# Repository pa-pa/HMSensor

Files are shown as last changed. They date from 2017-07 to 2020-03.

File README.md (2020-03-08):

# HMSensor

Flexible and tiny (40x20mm) Hardware Platform for 868MHz Sensors and Actors.

It comes in tow different variants:
* StepUp: For Batter or PowerSupply usage
* CR2032: For even smaller coin battery applications

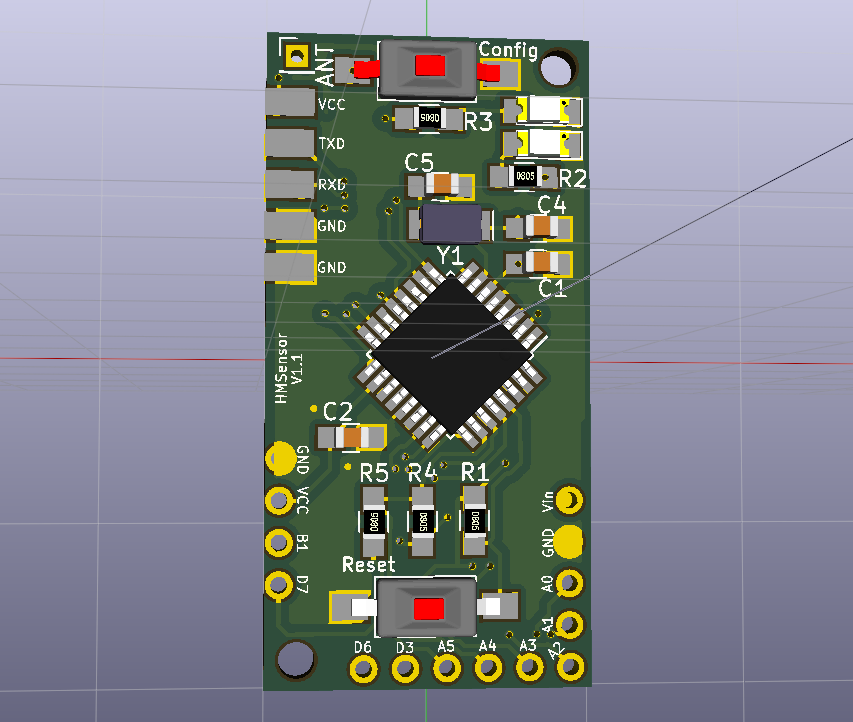
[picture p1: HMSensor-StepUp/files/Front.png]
HMSensor-StepUp


Extensible with [AddOn-Boards](AddOns).

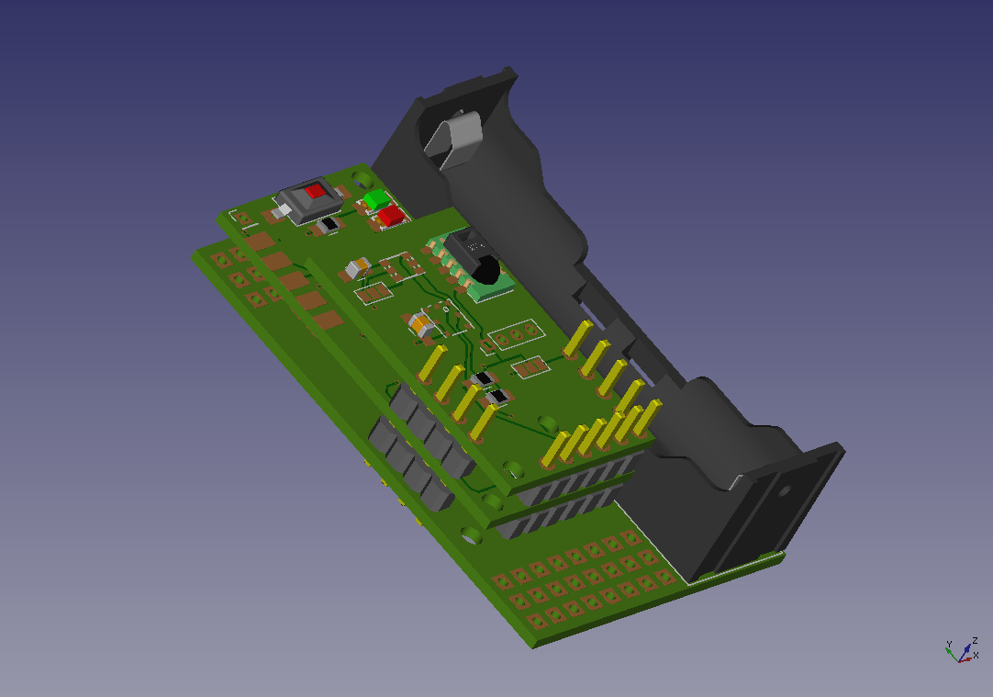
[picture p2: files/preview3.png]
AddOn Example


* Some (german) documentation is available at https://asksinpp.de/Projekte/psi/HMSensor
* Helper PCB for flashing: https://github.com/psi-4ward/HMSensor-FlashStation

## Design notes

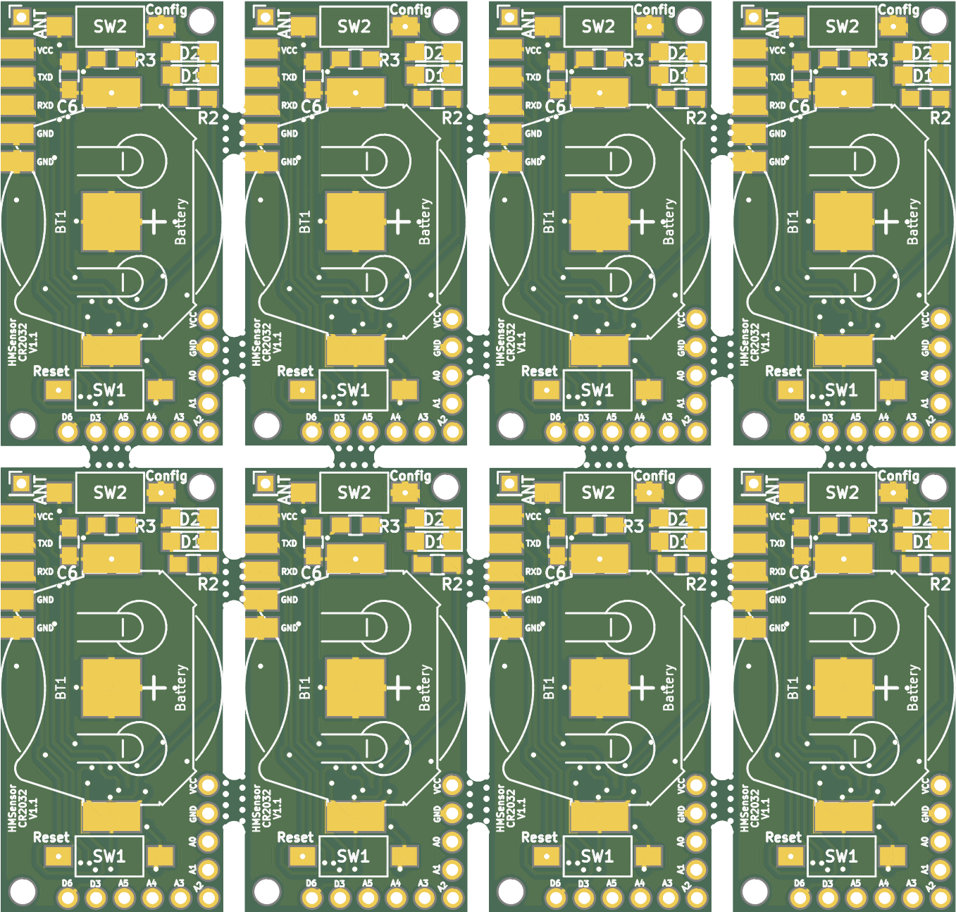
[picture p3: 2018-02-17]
HMSensor-CR2032/panel10/Untitled_Combined_Top.png

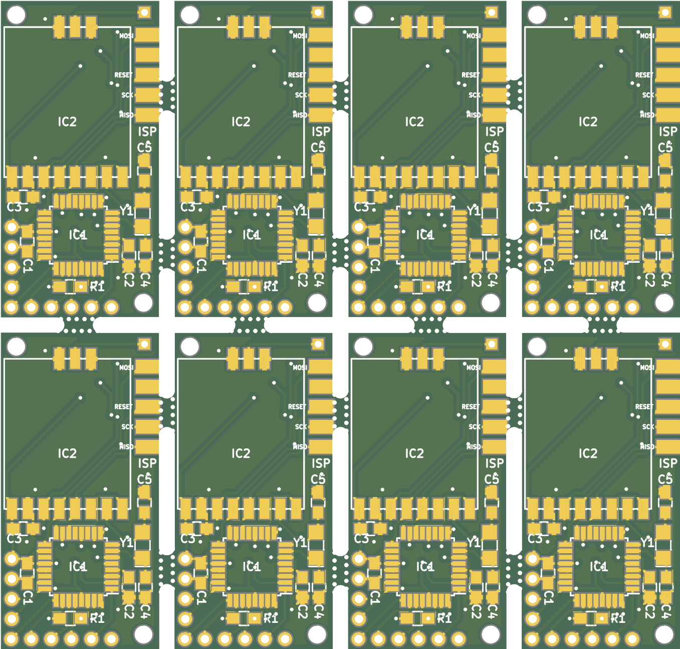
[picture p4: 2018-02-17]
HMSensor-CR2032/panel10/Untitled_Combined_Bottom.png

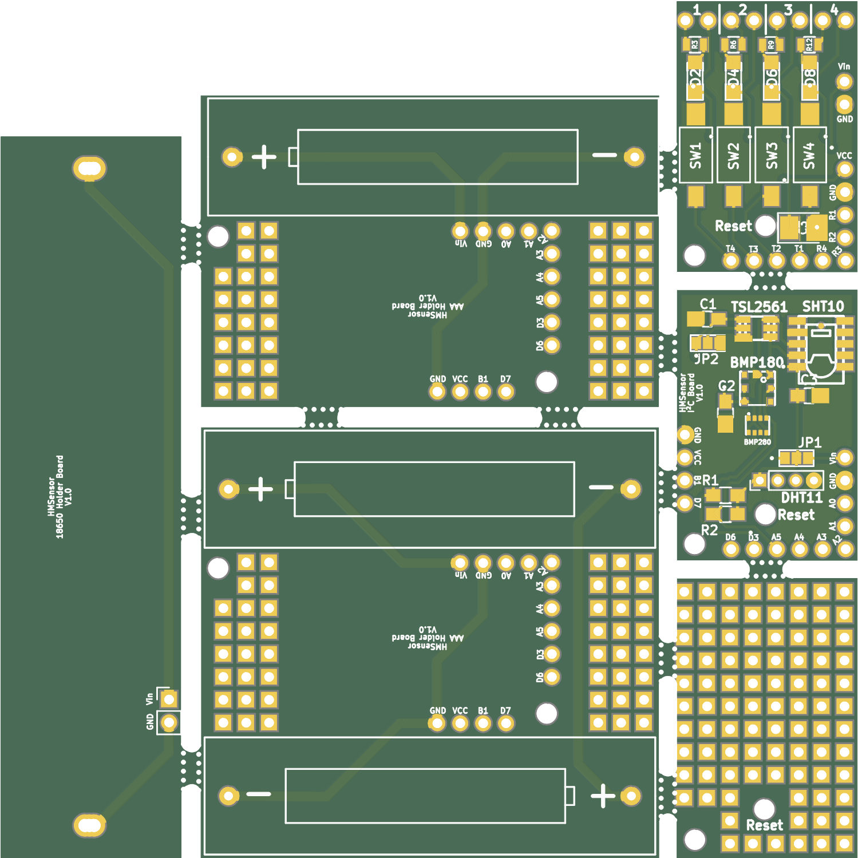
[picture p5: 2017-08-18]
Panel2/Untitled_Combined_Top.png

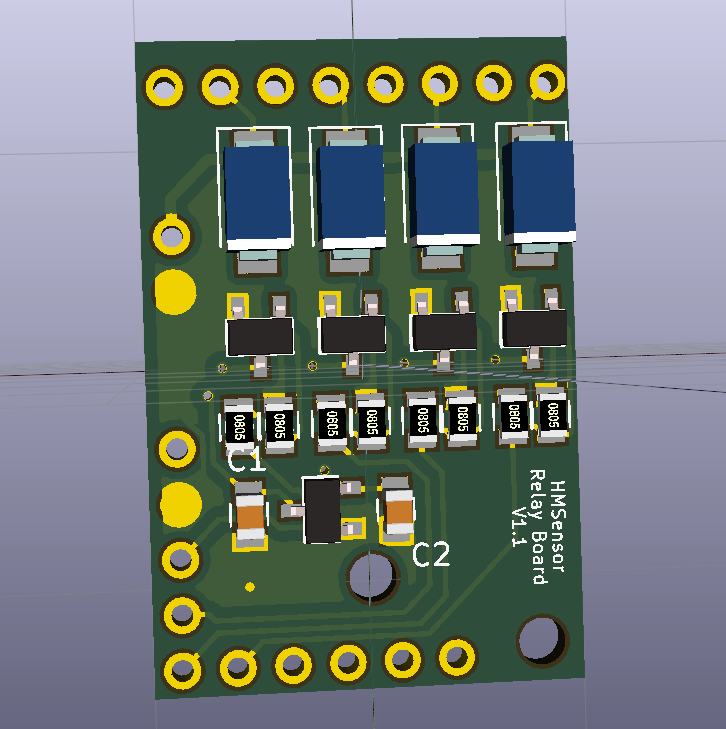
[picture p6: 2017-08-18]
AddOns/RelayBoard/files/RelayBoard-Back.png

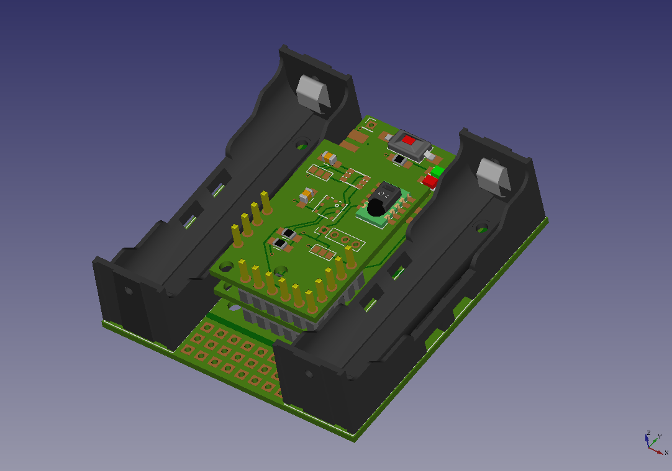
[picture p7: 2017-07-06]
files/preview2.png

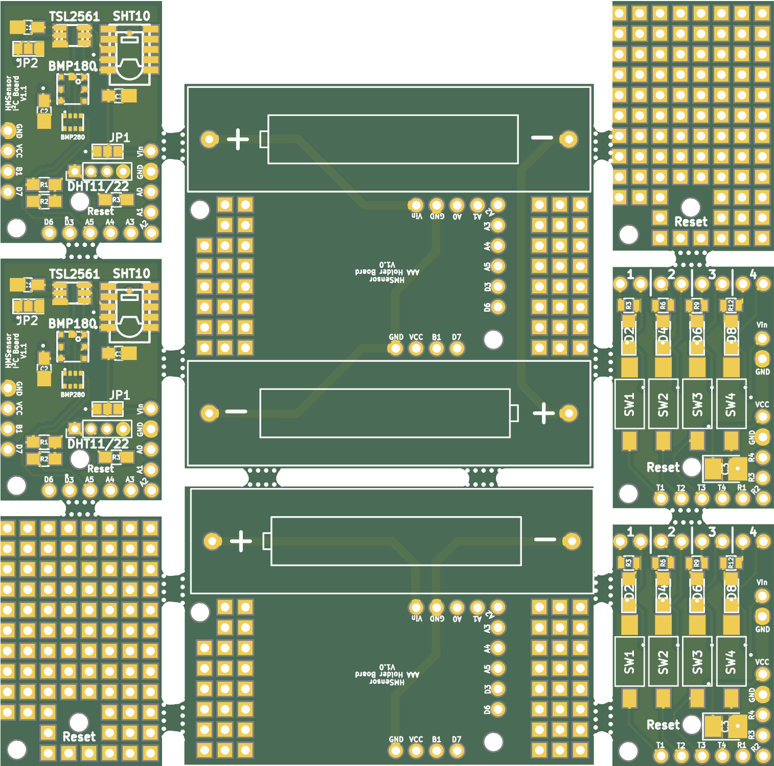
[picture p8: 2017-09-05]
Panel/P1_Combined_Top.png

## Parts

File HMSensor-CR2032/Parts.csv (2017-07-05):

Id | Designator | Package | Quantity | Designation | Supplier and ref
1 | P4 | Pin_Header_Straight_1x05_Pitch2.54mm_SMD_BySide | 1 | ISP Bottom
2 | P5 | Pin_Header_Straight_1x05_Pitch2.54mm_SMD_BySide | 1 | ISP Top
3 | IC1 | TQFP-32_7x7mm_Pitch0.8mm | 1 | ATMEGA328P-A
4 | P1 | Pin_Header_Straight_1x04_Pitch2.54mm | 1 | Contacts
5 | P2 | Pin_Header_Straight_1x06_Pitch2.54mm | 1 | Contacts
6 | BT1 | AB2_20MM_COIN_CELL_SMD | 1 | Battery
7 | IC2 | CC1101_Module | 1 | CC1101
8 | SW1 | SW_SPST_FSMSM | 1 | Reset
9 | SW2 | SW_SPST_FSMSM | 1 | Config
10 | C1,C2,C3 | C_0805_HandSoldering | 3 | 100n
11 | D1 | LED_1206 | 1 | LED Red
12 | D2 | LED_1206 | 1 | LED Green
13 | R1 | R_0805_HandSoldering | 1 | 10k
14 | R2,R3 | R_0805_HandSoldering | 2 | 1k5
15 | C4,C5 | C_0805_HandSoldering | 2 | 9p
16 | Y1 | Crystal_SMD_MicroCrystal_CC7V-T1A-2pin_3.2x1.5mm_HandSoldering | 1 | 32kHz
17 | REF**,REF** | MountingHole_2.2mm_M2 | 2 | MountingHole_2.2mm_M2
18 | P3 | Pin_Header_Straight_1x01_Pitch2.00mm | 1 | ANT
19 | C6 | C_0805_HandSoldering | 1 | 10µ

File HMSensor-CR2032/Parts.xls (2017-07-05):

Id | Designator | Package | Quantity | Designation | Supplier and ref
1 | P4 | Pin_Header_Straight_1x05_Pitch2.54mm_SMD_BySide | 1 | ISP Bottom
2 | P5 | Pin_Header_Straight_1x05_Pitch2.54mm_SMD_BySide | 1 | ISP Top
3 | IC1 | TQFP-32_7x7mm_Pitch0.8mm | 1 | ATMEGA328P-A | https://www.aliexpress.com/item/Free-Shipping-ATMEGA328P-AU-ATMEGA328P-ATMEGA328-8-bit-microcontroller-AVR-32-k-flash-memory-QFP-32/1913432637.html
4 | P1 | Pin_Header_Straight_1x04_Pitch2.54mm | 1 | Contacts
5 | P2 | Pin_Header_Straight_1x06_Pitch2.54mm | 1 | Contacts
6 | BT1 | AB2_20MM_COIN_CELL_SMD | 1 | Battery | https://www.aliexpress.com/item/50pcs-SMD-Tab-20mm-CR2032-2032-Battery-Button-Cell-Holder-Coin-Cell-Retainer-Battery-Holder-surface/32732961416.html
7 | IC2 | CC1101_Module | 1 | CC1101 | https://www.aliexpress.com/item/CC1101-Wireless-Module-Long-Distance-Transmission-Antenna-868MHZ-M115-Free-Shipping/32673344379.html
8 | SW1 | SW_SPST_FSMSM | 1 | Reset | https://www.aliexpress.com/item/Tact-Switch-SMD-small-button-touch-of-a-button-3-6-2-5MM-feet-3-6/32605670895.html
9 | SW2 | SW_SPST_FSMSM | 1 | Config | https://www.aliexpress.com/item/Tact-Switch-SMD-small-button-touch-of-a-button-3-6-2-5MM-feet-3-6/32605670895.html
10 | C1,C2,C3 | C_0805_HandSoldering | 3 | 100n | https://www.aliexpress.com/item/100pcs-lot-100nF-X7R-Error-10-50V-0805-SMD-Thick-Film-Chip-Multilayer-Ceramic-Capacitor-free/32318938808.html
11 | D1 | LED_1206 | 1 | LED Red | https://de.aliexpress.com/item/100PCS-LOT-1206-Red-SMD-LED-Diode-Light-3216-Diodes-SMD-Super-Bright-1206-led-3/32623813733.html
12 | D2 | LED_1206 | 1 | LED Green | https://de.aliexpress.com/item/100PCS-LOT-1206-Green-SMD-LED-Diode-Light-3216-Diodes-SMD-Super-Bright-1206-led-3/32623837500.html
13 | R1 | R_0805_HandSoldering | 1 | 10k | https://www.aliexpress.com/item/SMD-Resistance-0805-10k-1-1-8W-Chip-Resistors-100PCS-LOT/32520849440.html
14 | R2,R3 | R_0805_HandSoldering | 2 | 1k5 | https://www.aliexpress.com/item/Free-shipping-100pcs-lot-SMD-Chip-Resistor-1-0805-1-5K-1500-OHMS-1-8W-100/32568078790.html
15 | C4,C5 | C_0805_HandSoldering | 2 | 9p | https://www.aliexpress.com/item/100pcs-lot-12pF-NPO-Error-5-50V-0805-smd-capacitor/32319279542.html
16 | Y1 | Crystal_SMD_MicroCrystal_CC7V-T1A-2pin_3.2x1.5mm_HandSoldering | 1 | 32kHz | https://www.aliexpress.com/item/3215-32-768K-32-768KHZ-MICRO-CC7V-T1A-2P-SMD-Crystal-Oscillator-x-50PCS/1990577957.html
17 | REF**,REF** | MountingHole_2.2mm_M2 | 2 | MountingHole_2.2mm_M2
18 | P3 | Pin_Header_Straight_1x01_Pitch2.00mm | 1 | ANT
19 | C6 | C_0805_HandSoldering | 1 | 10µ | https://www.aliexpress.com/item/100pcs-lot-10uF-X5R-Error-10-10V-0805-SMD-Thick-Film-Chip-Multilayer-Ceramic-Capacitor/32318125532.html

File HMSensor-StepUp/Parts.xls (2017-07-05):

Id | Designator | Package | Quantity | Designation | Supplier and ref
1 | P4 | Pin_Header_Straight_1x05_Pitch2.54mm_SMD_BySide | 1 | ISP Bottom
2 | P5 | Pin_Header_Straight_1x05_Pitch2.54mm_SMD_BySide | 1 | ISP Top
3 | IC1 | TQFP-32_7x7mm_Pitch0.8mm | 1 | ATMEGA328P-A | https://www.aliexpress.com/item/Free-Shipping-ATMEGA328P-AU-ATMEGA328P-ATMEGA328-8-bit-microcontroller-AVR-32-k-flash-memory-QFP-32/1913432637.html
4 | P1 | Pin_Header_Straight_1x04_Pitch2.54mm | 1 | Contacts
5 | P2 | Pin_Header_Straight_1x06_Pitch2.54mm | 1 | Contacts
7 | IC2 | CC1101_Module | 1 | CC1101 | https://www.aliexpress.com/item/CC1101-Wireless-Module-Long-Distance-Transmission-Antenna-868MHZ-M115-Free-Shipping/32673344379.html
8 | SW1 | SW_SPST_FSMSM | 1 | Reset | https://www.aliexpress.com/item/Tact-Switch-SMD-small-button-touch-of-a-button-3-6-2-5MM-feet-3-6/32605670895.html
9 | SW2 | SW_SPST_FSMSM | 1 | Config | https://www.aliexpress.com/item/Tact-Switch-SMD-small-button-touch-of-a-button-3-6-2-5MM-feet-3-6/32605670895.html
10 | C1,C2,C3 | C_0805_HandSoldering | 3 | 100n | https://www.aliexpress.com/item/100pcs-lot-100nF-X7R-Error-10-50V-0805-SMD-Thick-Film-Chip-Multilayer-Ceramic-Capacitor-free/32318938808.html
11 | D1 | LED_1206 | 1 | LED Red | https://de.aliexpress.com/item/100PCS-LOT-1206-Red-SMD-LED-Diode-Light-3216-Diodes-SMD-Super-Bright-1206-led-3/32623813733.html
12 | D2 | LED_1206 | 1 | LED Green | https://de.aliexpress.com/item/100PCS-LOT-1206-Green-SMD-LED-Diode-Light-3216-Diodes-SMD-Super-Bright-1206-led-3/32623837500.html
13 | R1 | R_0805_HandSoldering | 1 | 10k | https://www.aliexpress.com/item/SMD-Resistance-0805-10k-1-1-8W-Chip-Resistors-100PCS-LOT/32520849440.html
14 | R2,R3 | R_0805_HandSoldering | 2 | 1k5 | https://www.aliexpress.com/item/Free-shipping-100pcs-lot-SMD-Chip-Resistor-1-0805-1-5K-1500-OHMS-1-8W-100/32568078790.html
15 | R4 | R_0805_HandSoldering | 1 | 470k | https://de.aliexpress.com/store/product/100pcs-lot-SMD-Chip-Resistor-0805-470K-470K-ohm-5-Free-shippng/430356_32381673551.html
16 | R5 | R_0805_HandSoldering | 1 | 100k | https://de.aliexpress.com/item/100pcs-lot-SMD-Chip-Resistor-0805-100K-100K-ohm-5-Free-shippng/32383238614.html
17 | C4,C5 | C_0805_HandSoldering | 2 | 9p | https://www.aliexpress.com/item/100pcs-lot-12pF-NPO-Error-5-50V-0805-smd-capacitor/32319279542.html
18 | Y1 | Crystal_SMD_MicroCrystal_CC7V-T1A-2pin_3.2x1.5mm_HandSoldering | 1 | 32kHz | https://www.aliexpress.com/item/3215-32-768K-32-768KHZ-MICRO-CC7V-T1A-2P-SMD-Crystal-Oscillator-x-50PCS/1990577957.html
19 | REF**,REF** | MountingHole_2.2mm_M2 | 2 | MountingHole_2.2mm_M2
20 | P3 | Pin_Header_Straight_1x01_Pitch2.00mm | 1 | ANT
21 | C6,C7 | C_0805_HandSoldering | 2 | 10µ | https://www.aliexpress.com/item/100pcs-lot-10uF-X5R-Error-10-10V-0805-SMD-Thick-Film-Chip-Multilayer-Ceramic-Capacitor/32318125532.html
22 | IC3 | SOT-363_SC-70-6_Handsoldering | 1 | TLV61224 | https://www.aliexpress.com/item/AD364SD/32636036886.html
23 | L1 | SMD-1210_Pol | 1 | 4,7µH | https://www.aliexpress.com/item/1210-4-7UH-Multilayer-Chip-Inductors-3225-4R7J-Inductance-50Pcs-Lot-Free-shipping/32430574328.html

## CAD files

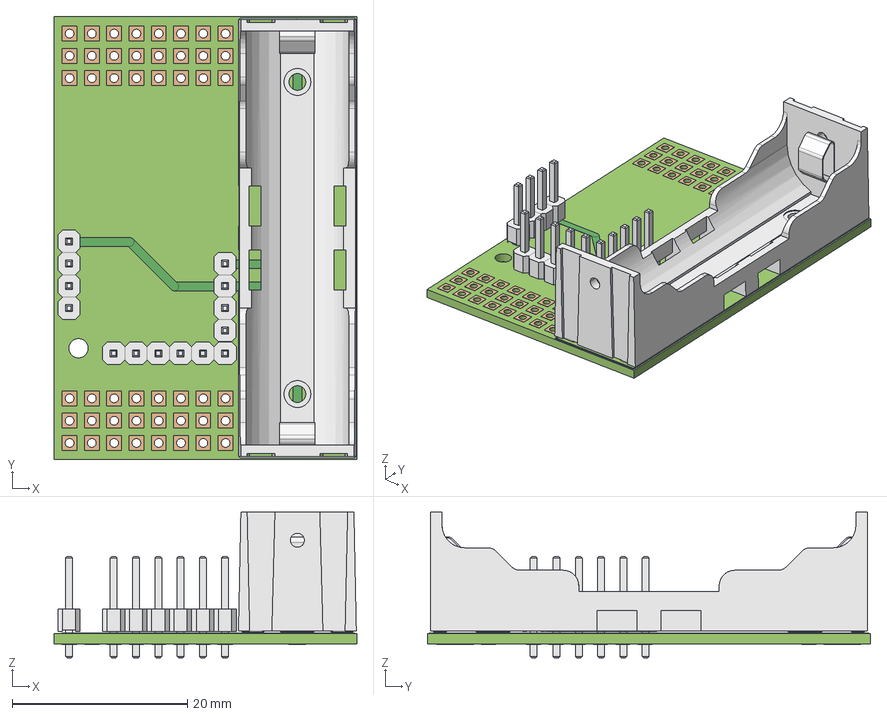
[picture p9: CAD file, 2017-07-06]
AddOns/1AAAHolder/1AAAHolder.FCStd
34.5 x 50.5 x 16.6 mm
Board
P6
P1
P2
REF**049
F_Cu_0
bPad_107
tPad_108
F_SilkS_37

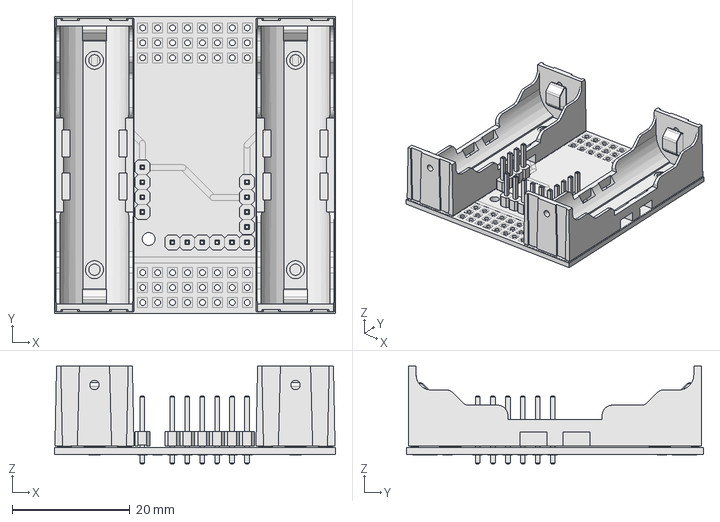
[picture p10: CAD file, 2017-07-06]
AddOns/2AAAHolder/2AAAHolder_1.FCStd
47.8 x 50.5 x 16.6 mm

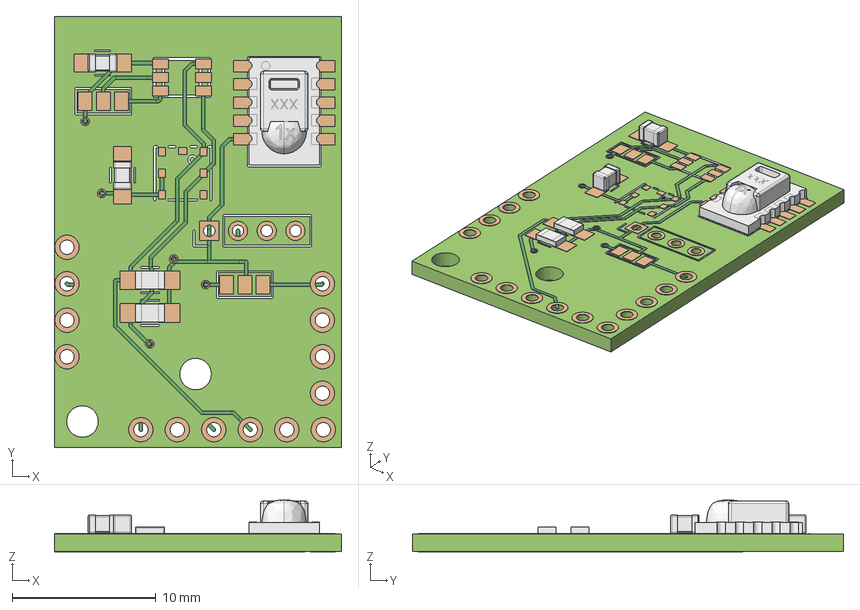
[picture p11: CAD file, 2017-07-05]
AddOns/I2CBoard/I2CBoard.FCStd
20.0 x 30.0 x 3.61 mm
Board
C1
C2
R1
R2
U1
F_Cu_0
bPad_107
tPad_108
B_Cu_31
F_SilkS_37

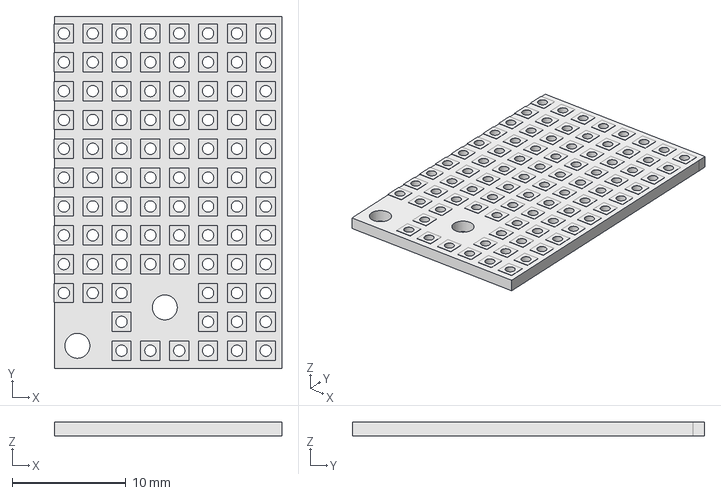
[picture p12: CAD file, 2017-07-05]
AddOns/PrototypeBoard/PrototypeBoard_1.FCStd
20.0 x 31.0 x 1.27 mm

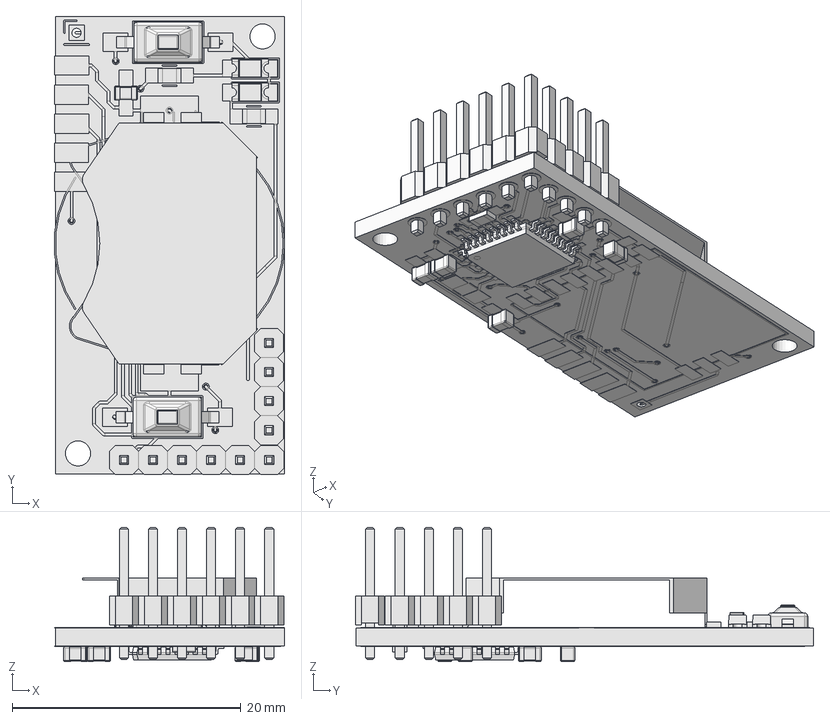
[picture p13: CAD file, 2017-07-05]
HMSensor-CR2032/HMSensor-CR2032_1.FCStd
20.1 x 40.0 x 11.7 mm

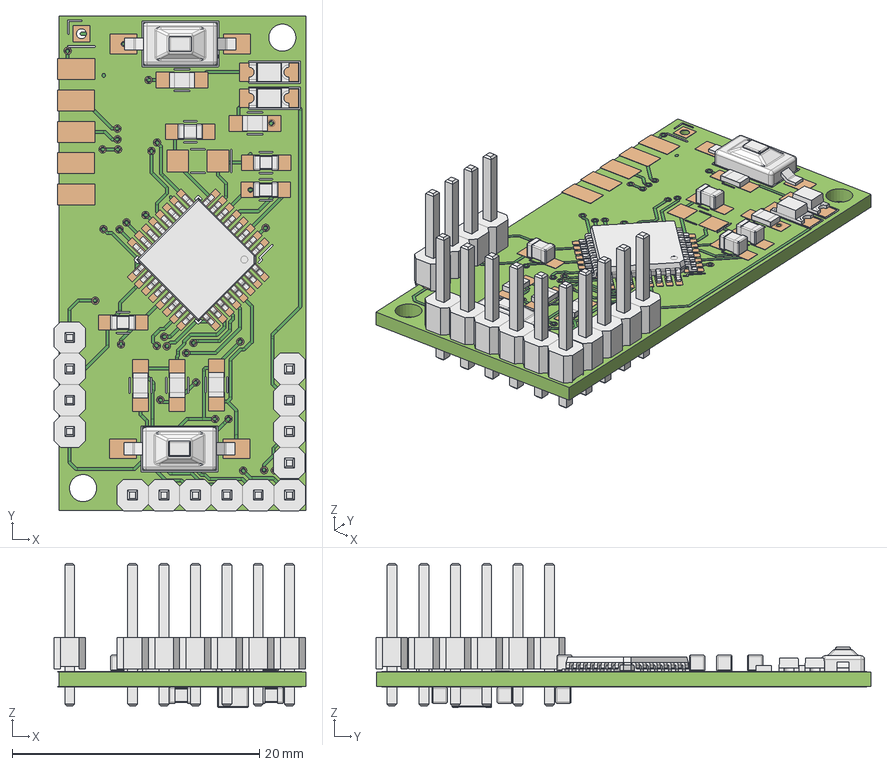
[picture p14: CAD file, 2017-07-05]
HMSensor-StepUp/HMSensor-StepUp.FCStd
20.4 x 40.0 x 11.7 mm
Board
P6
IC1
P1
P2
SW1
SW2
C1
C3
R1
R2
R3
C4
C5
C6
C7
IC3
L1
R4
C2
R5
D1
D2
F_Cu_0
bPad_107
tPad_108
B_Cu_31
B_SilkS_36
F_SilkS_37

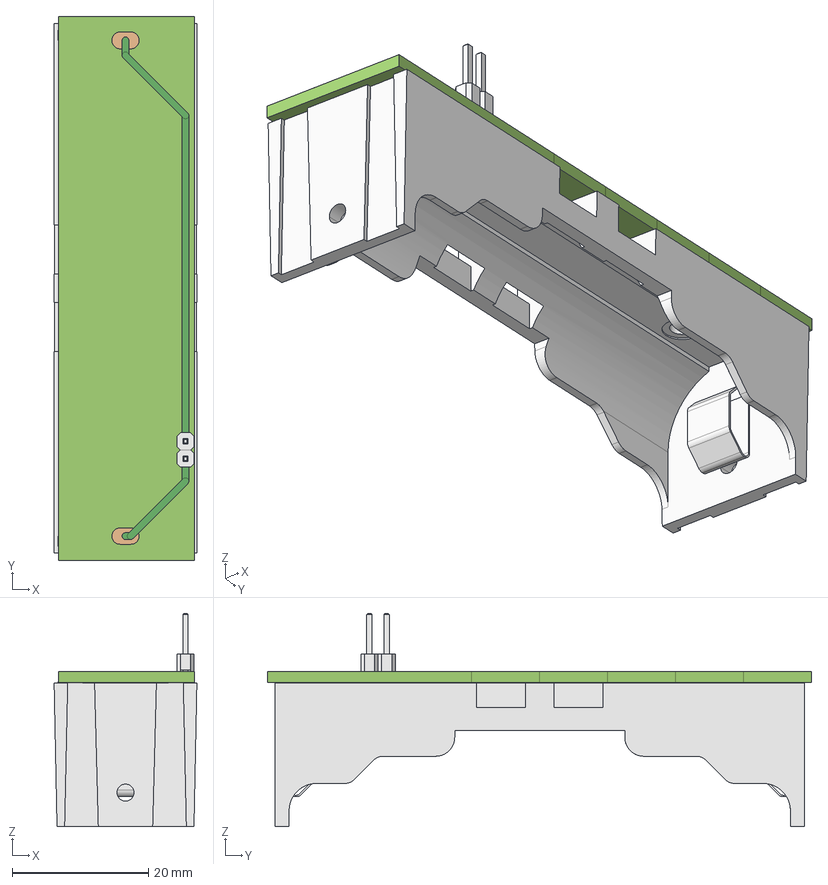
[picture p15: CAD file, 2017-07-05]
AddOns/18650Holder/18650Holder.FCStd
21.0 x 80.0 x 31.4 mm
Board
REF**
REF**001
F_Cu_0
bPad_107
tPad_108

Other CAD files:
AddOns/1AAAHolder/1AAAHolder_1.FCStd
AddOns/2AAAHolder/2AAAHolder.FCStd
AddOns/I2CBoard/I2CBoard_1.FCStd
AddOns/PrototypeBoard/PrototypeBoard.FCStd
HMSensor-CR2032/HMSensor-CR2032.FCStd
HMSensor-StepUp/HMSensor-StepUp_1.FCStd
AddOns/18650Holder/18650Holder_1.FCStd

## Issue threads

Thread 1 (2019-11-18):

part list s old

MathiasJZ, 2019-11-18:
I want to build my window handle state sensor.
https://github.com/pa-pa/HMSensor/blob/master/HMSensor-CR2032/Parts.xls
But links most are not working.
It's not better to insert a complete type designation of all electronic elements instead of broken links?
Thank you in advance.
Mathias

pa-pa, 2019-11-18:
You are welcome to update the list

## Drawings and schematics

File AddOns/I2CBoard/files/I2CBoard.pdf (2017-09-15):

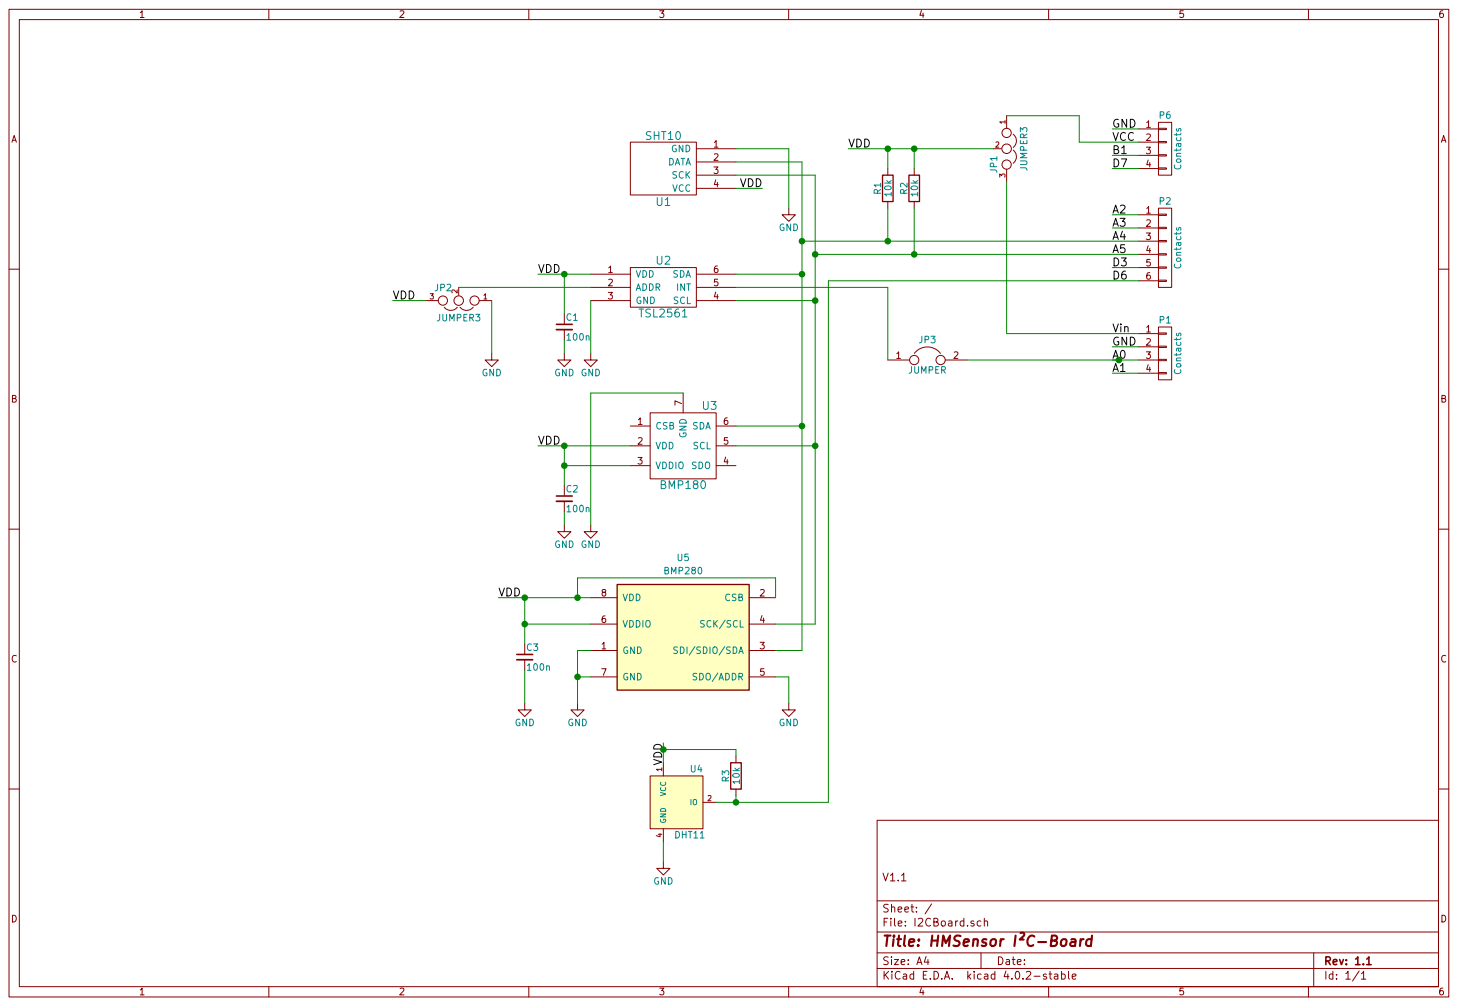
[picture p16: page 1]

Id: 1/1 Title: HMSensor I²C-Board

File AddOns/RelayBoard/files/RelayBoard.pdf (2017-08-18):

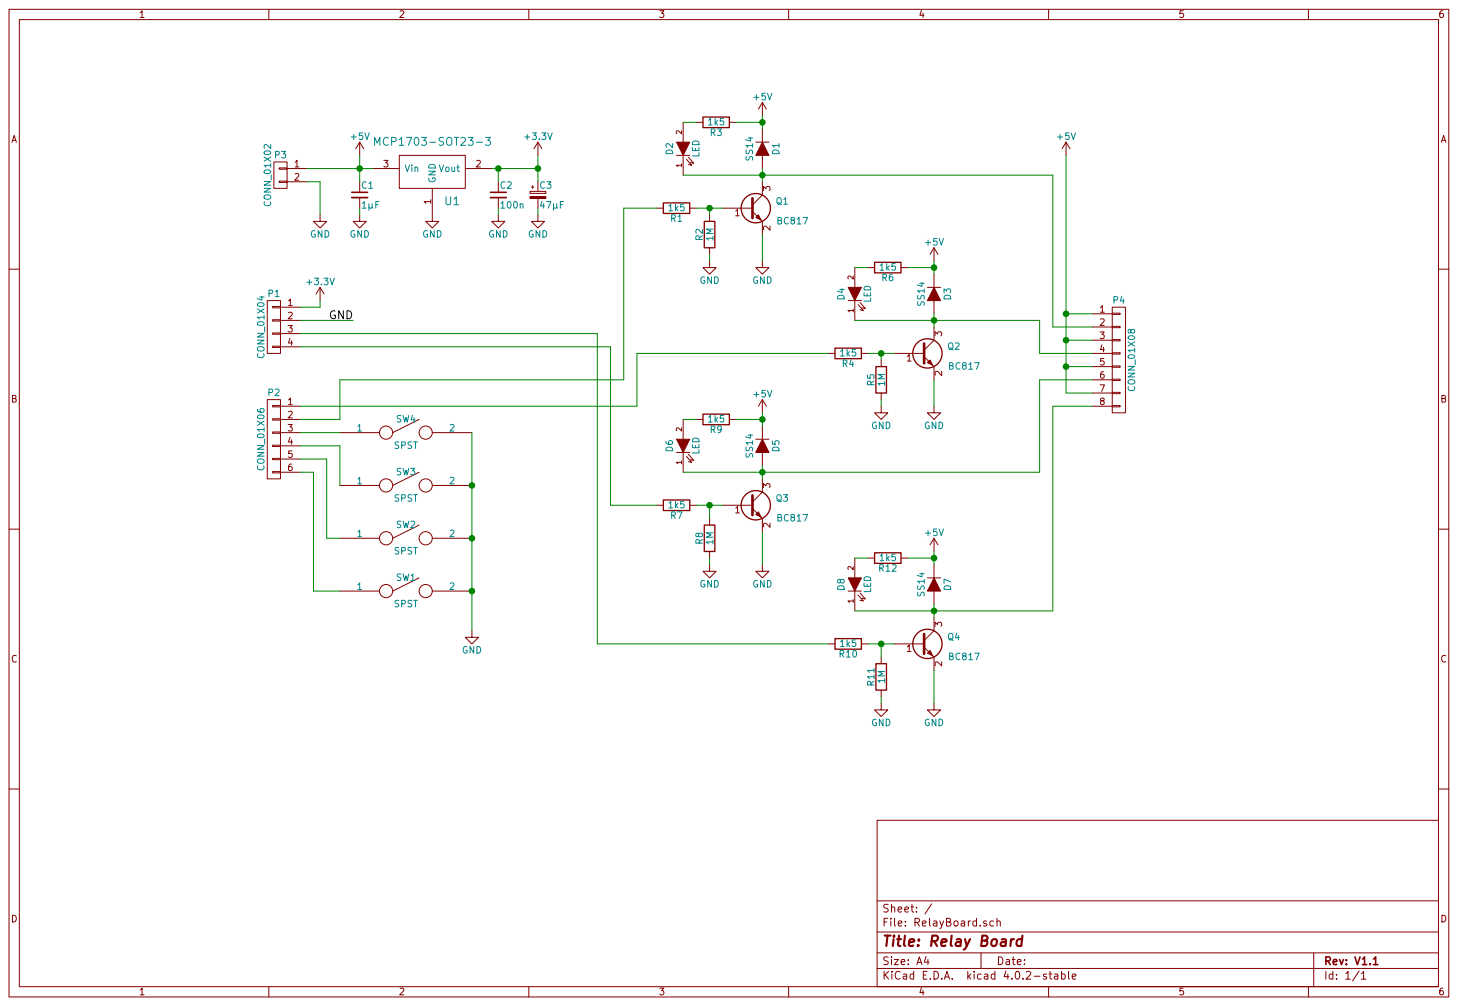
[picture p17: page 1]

Id: 1/1 Title: Relay Board

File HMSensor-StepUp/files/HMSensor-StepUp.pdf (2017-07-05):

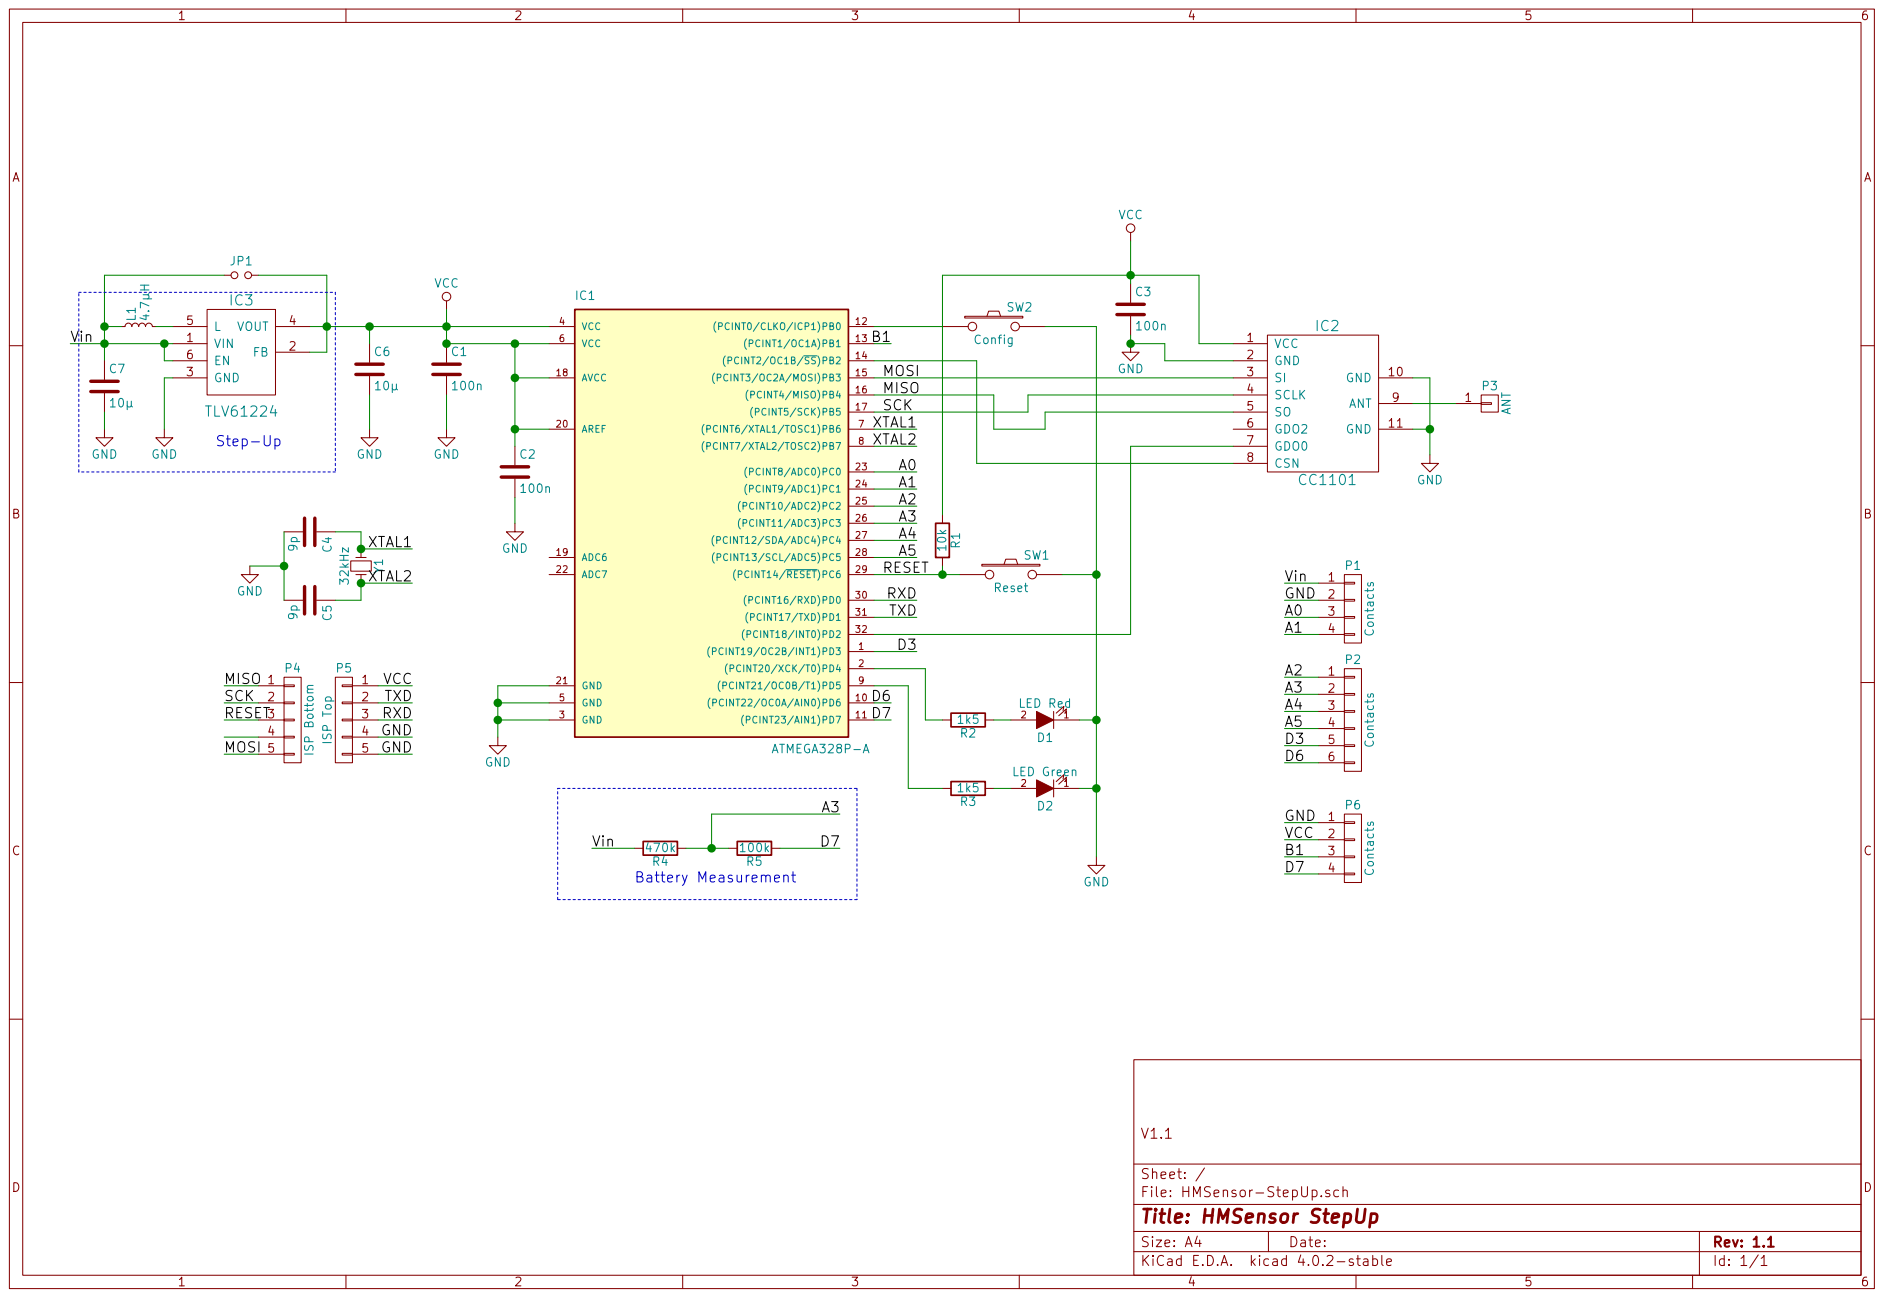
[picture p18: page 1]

File: HMSensor-StepUp.sch Sheet: / V1.1

Id: 1/1 Title: HMSensor StepUp

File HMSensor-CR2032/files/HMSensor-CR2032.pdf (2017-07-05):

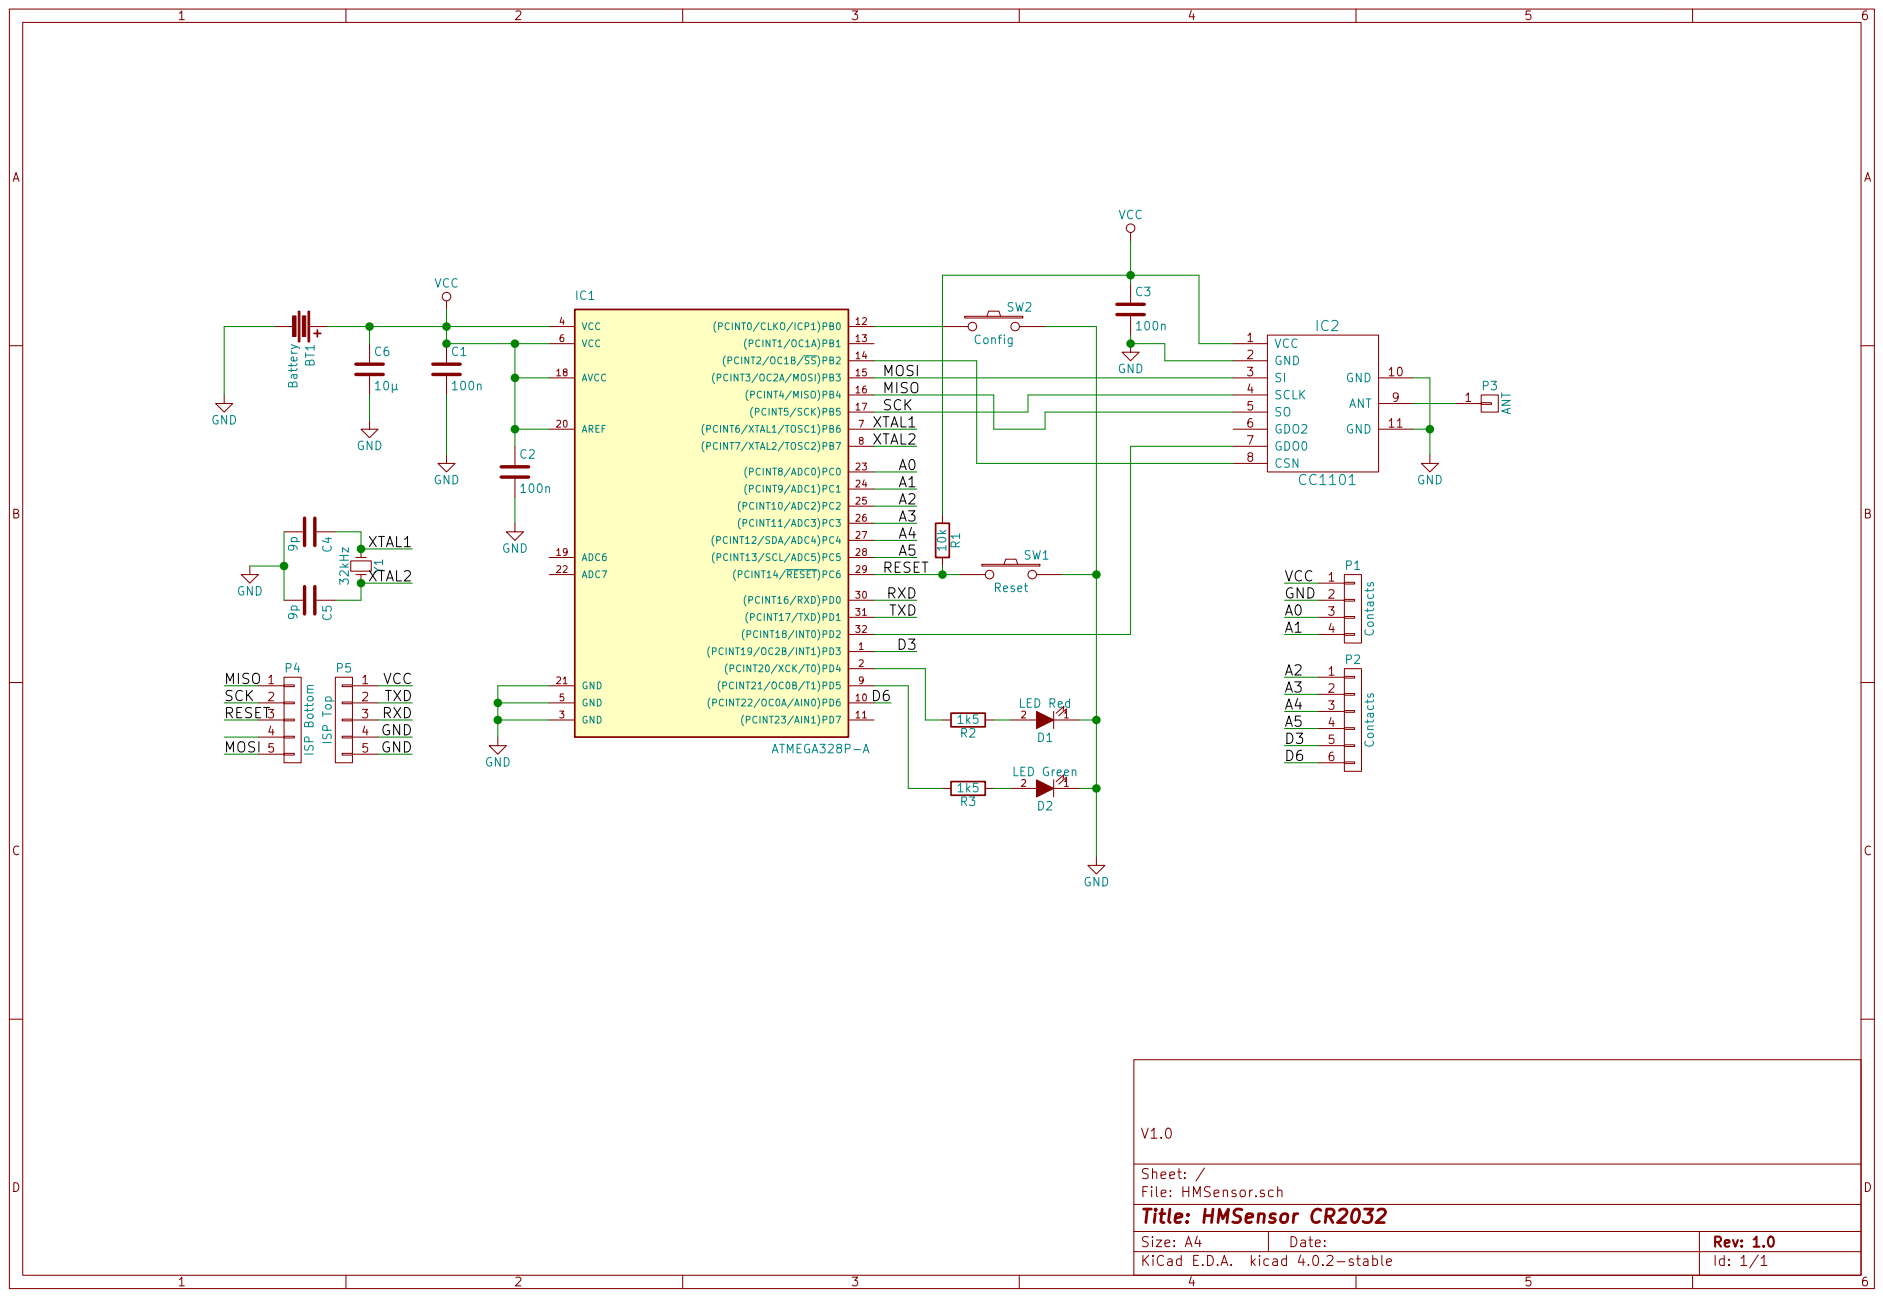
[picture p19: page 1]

File: HMSensor.sch Sheet: / V1.0

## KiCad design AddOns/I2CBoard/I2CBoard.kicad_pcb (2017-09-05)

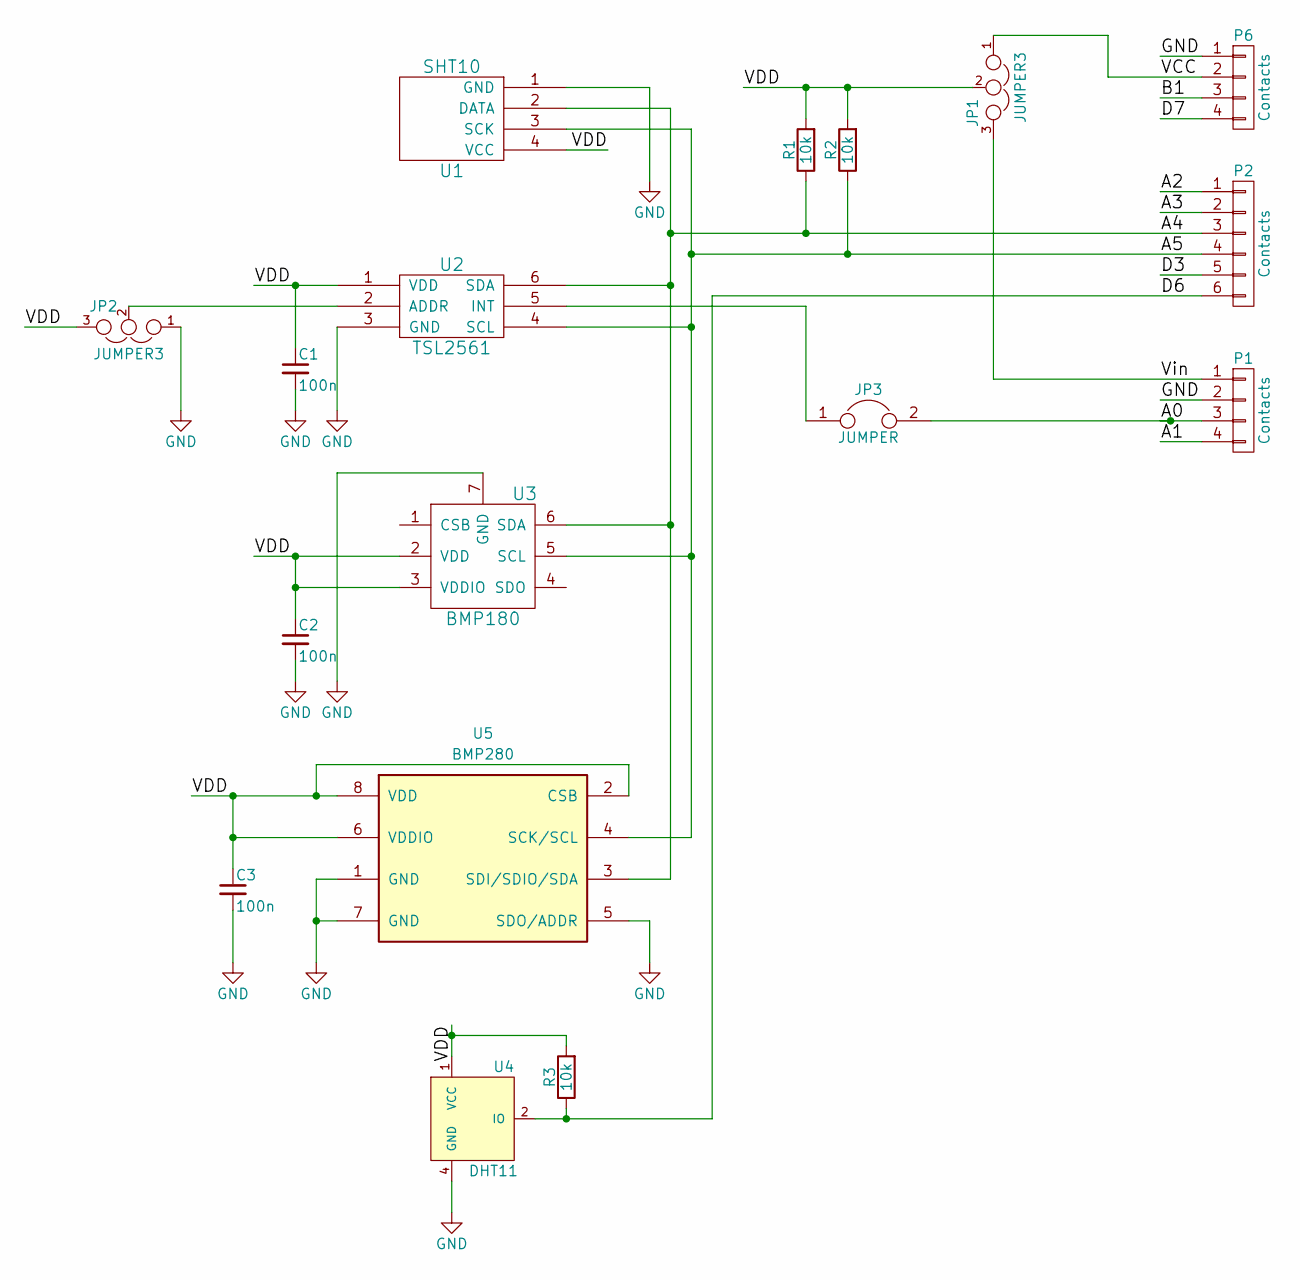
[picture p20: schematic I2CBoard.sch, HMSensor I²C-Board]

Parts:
C1, C2, C3: 100n; C_0805_HandSoldering
JP1, JP2: JUMPER3; GS3
JP3: JUMPER; GS2
P1, P6: Contacts; Pin_Header_Straight_1x04_Pitch2.54mm
P2: Contacts; Pin_Header_Straight_1x06_Pitch2.54mm
R1, R2, R3: 10k; R_0805_HandSoldering
U1: SHT10; SHT1x
U2: TSL2561; TSL256x
U3: BMP180; LGA_BMP180
U4: DHT11; Pin_Header_Straight_1x04_Pitch2.00mm
U5: BMP280; BOSCH_BMP280; MPN BMP280

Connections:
/A0: JP3.2, P1.3
/A1: P1.4
/A2: P2.1
/A3: P2.2
/A4: P2.3, R1.1, U1.2 (DATA), U2.6 (SDA), U3.6 (SDA), U5.3 (SDI/SDIO/SDA)
/A5: P2.4, R2.1, U1.3 (SCK), U2.4 (SCL), U3.5 (SCL), U5.4 (SCK/SCL)
/B1: P6.3
/D3: P2.5
/D6: P2.6, R3.1, U4.2 (IO)
/D7: P6.4
/VCC: JP1.1, P6.2
/VDD: C1.1, C2.1, C3.1, JP1.2, JP2.3, R1.2, R2.2, R3.2, U1.4 (VCC), U2.1 (VDD), U3.2 (VDD), U3.3 (VDDIO), U4.1 (VCC), U5.2 (CSB), U5.6 (VDDIO), U5.8 (VDD)
/Vin: JP1.3, P1.1
GND: C1.2, C2.2, C3.2, JP2.1, P1.2, P6.1, U1.1 (GND), U2.3 (GND), U3.7 (GND), U4.4 (GND), U5.1 (GND), U5.5 (SDO/ADDR), U5.7 (GND)
unnamed: JP2.2, U2.2 (ADDR)
unnamed: JP3.1, U2.5 (INT)

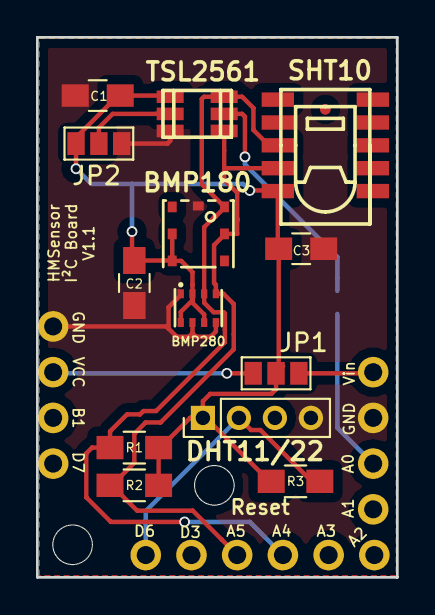
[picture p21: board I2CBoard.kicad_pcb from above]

Board: 2 copper layers, 20.0 x 30.0 mm, 17 parts (1 on the bottom side), 10 nets.

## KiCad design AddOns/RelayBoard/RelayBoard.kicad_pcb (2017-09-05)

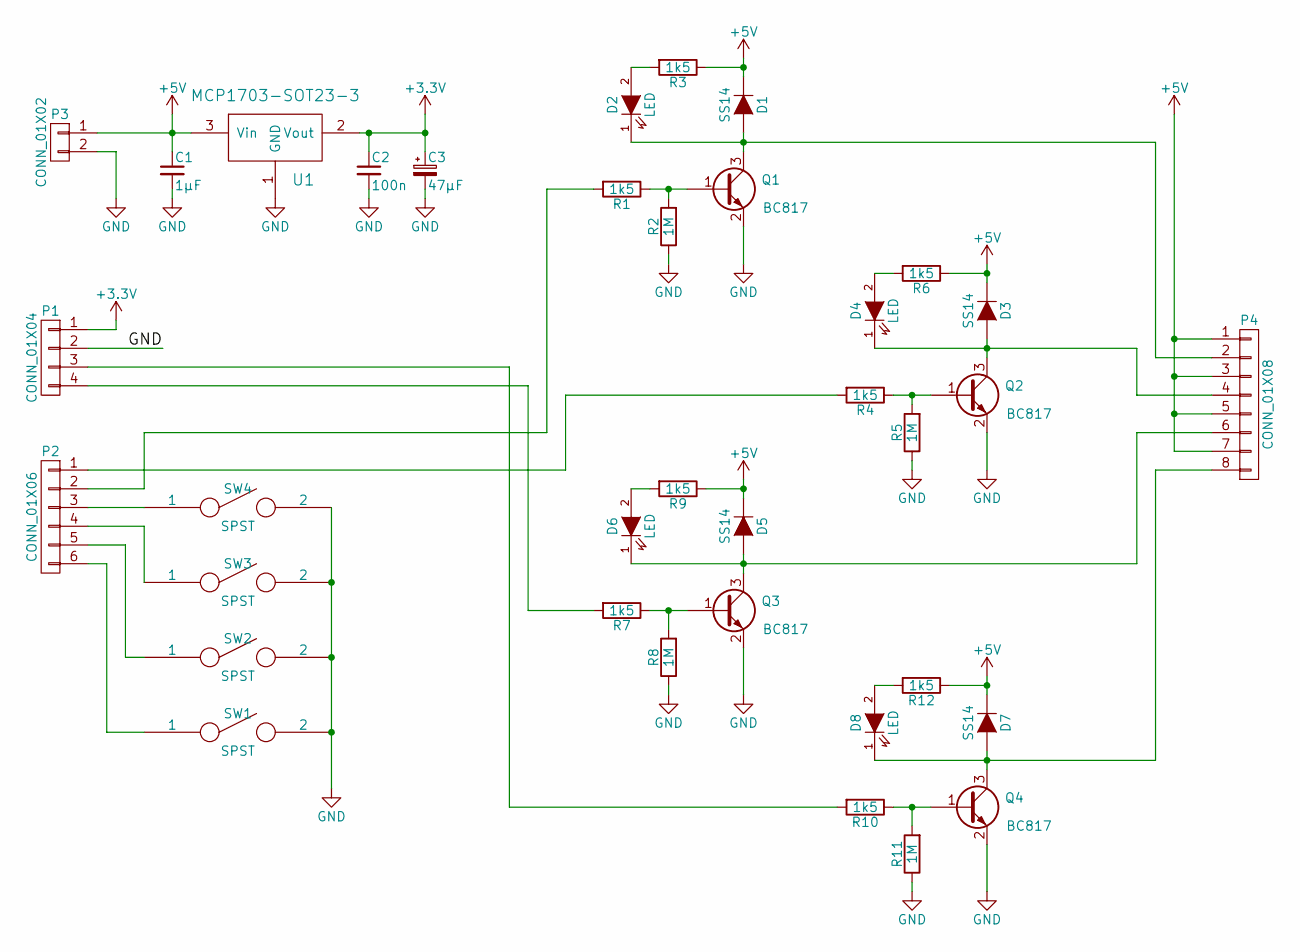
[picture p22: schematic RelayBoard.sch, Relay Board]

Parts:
C1: 1µF; C_0805
C2: 100n; C_0805
C3: 47µF; CP_Tantalum_Case-T_EIA-3528-12_Reflow
D1, D3, D5, D7: SS14; D_SMA
D2, D4, D6, D8: LED; LED_1206
P1: CONN_01X04; Pin_Header_Straight_1x04_Pitch2.54mm
P2: CONN_01X06; Pin_Header_Straight_1x06_Pitch2.54mm
P3: CONN_01X02; Pin_Header_Straight_1x02_Pitch2.54mm
P4: CONN_01X08; Pin_Header_Straight_1x08_Pitch2.54mm
Q1, Q2, Q3, Q4: BC817; SOT-23-3
R1, R3, R4, R6, R7, R9, R10, R12: 1k5; R_0805
R2, R5, R8, R11: 1M; R_0805
SW1, SW2, SW3, SW4: SPST; SW_SPST_FSMSM
U1: MCP1703-SOT23-3; SOT-23-3

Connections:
+3V3: C2.1, C3.1, P1.1, U1.2 (Vout)
+5V: C1.1, D1.1 (K), D3.1 (K), D5.1 (K), D7.1 (K), P3.1, P4.1, P4.3, P4.5, P4.7, R3.1, R6.1, R9.1, R12.1, U1.3 (Vin)
GND: C1.2, C2.2, C3.2, P1.2, P3.2, Q1.2 (E), Q2.2 (E), Q3.2 (E), Q4.2 (E), R2.1, R5.1, R8.1, R11.1, SW1.2, SW2.2, SW3.2, SW4.2, U1.1 (GND)
unnamed: D1.2 (A), D2.1 (K), P4.2, Q1.3 (C)
unnamed: D2.2 (A), R3.2
unnamed: D3.2 (A), D4.1 (K), P4.4, Q2.3 (C)
unnamed: D4.2 (A), R6.2
unnamed: D5.2 (A), D6.1 (K), P4.6, Q3.3 (C)
unnamed: D6.2 (A), R9.2
unnamed: D7.2 (A), D8.1 (K), P4.8, Q4.3 (C)
unnamed: D8.2 (A), R12.2
unnamed: P1.3, R10.2
unnamed: P1.4, R7.2
unnamed: P2.1, R4.2
unnamed: P2.2, R1.2
unnamed: P2.3, SW4.1
unnamed: P2.4, SW3.1
unnamed: P2.5, SW2.1
unnamed: P2.6, SW1.1
unnamed: Q1.1 (B), R1.1, R2.2
unnamed: Q2.1 (B), R4.1, R5.2
unnamed: Q3.1 (B), R7.1, R8.2
unnamed: Q4.1 (B), R10.1, R11.2

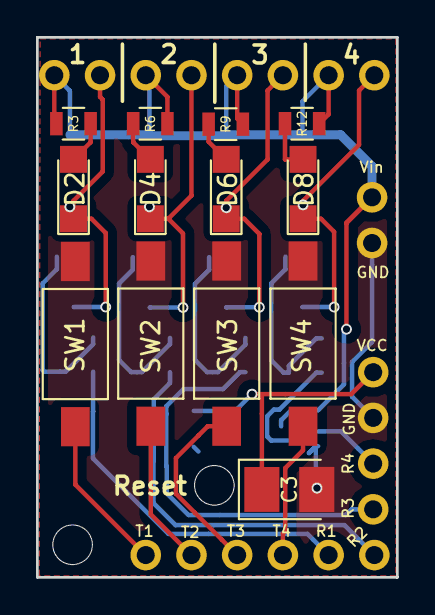
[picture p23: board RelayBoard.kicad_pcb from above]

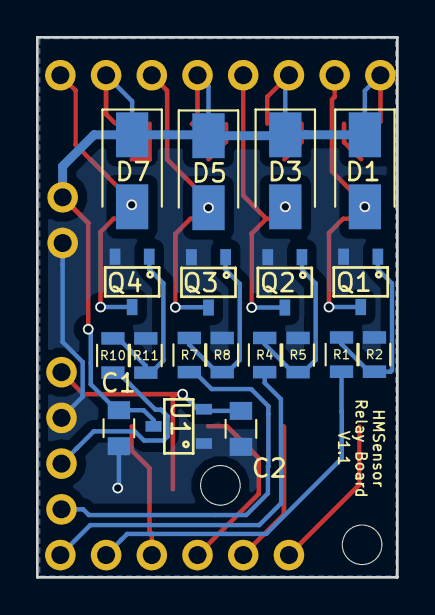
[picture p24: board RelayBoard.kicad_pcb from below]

Board: 2 copper layers, 20.0 x 30.0 mm, 36 parts (19 on the bottom side), 23 nets.

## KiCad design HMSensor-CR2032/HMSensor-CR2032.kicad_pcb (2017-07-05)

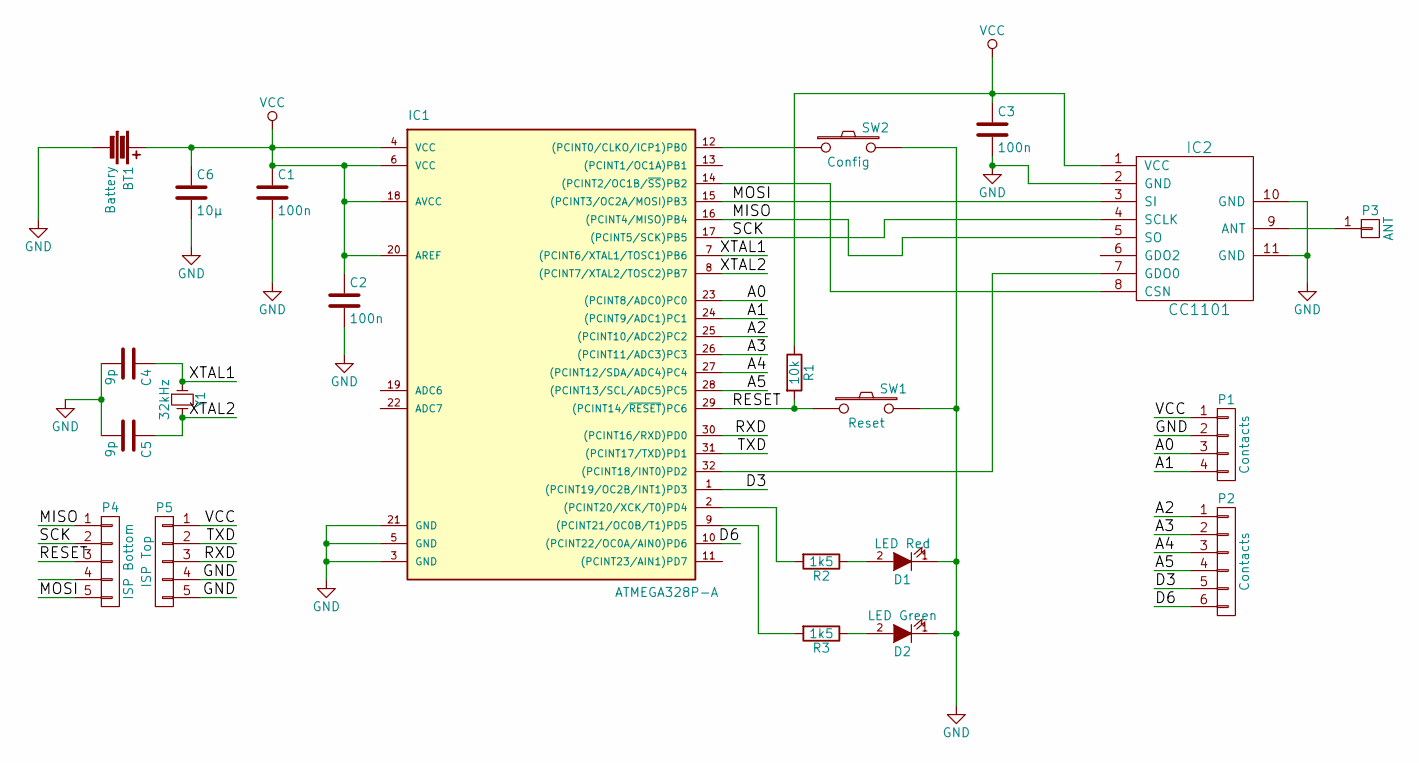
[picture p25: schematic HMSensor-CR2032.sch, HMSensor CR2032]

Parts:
BT1: Battery; AB2_20MM_COIN_CELL_SMD
C1, C2, C3: 100n; C_0805_HandSoldering
C4, C5: 9p; C_0805_HandSoldering
C6: 10µ; C_0805_HandSoldering
D1: LED Red; LED_1206
D2: LED Green; LED_1206
IC1: ATMEGA328P-A; TQFP-32_7x7mm_Pitch0.8mm
IC2: CC1101; CC1101_Module
P1: Contacts; Pin_Header_Straight_1x04_Pitch2.54mm
P2: Contacts; Pin_Header_Straight_1x06_Pitch2.54mm
P3: ANT; Pin_Header_Straight_1x01_Pitch2.00mm
P4: ISP Bottom; Pin_Header_Straight_1x05_Pitch2.54mm_SMD_BySide
P5: ISP Top; Pin_Header_Straight_1x05_Pitch2.54mm_SMD_BySide
R1: 10k; R_0805_HandSoldering
R2, R3: 1k5; R_0805_HandSoldering
SW1: Reset; SW_SPST_FSMSM
SW2: Config; SW_SPST_FSMSM
Y1: 32kHz; Crystal_SMD_MicroCrystal_CC7V-T1A-2pin_3.2x1.5mm_HandSolder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

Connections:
/A0: IC1.23 ((PCINT8/ADC0)PC0), P1.3
/A1: IC1.24 ((PCINT9/ADC1)PC1), P1.4
/A2: IC1.25 ((PCINT10/ADC2)PC2), P2.1
/A3: IC1.26 ((PCINT11/ADC3)PC3), P2.2
/A4: IC1.27 ((PCINT12/SDA/ADC4)PC4), P2.3
/A5: IC1.28 ((PCINT13/SCL/ADC5)PC5), P2.4
/D3: IC1.1 ((PCINT19/OC2B/INT1)PD3), P2.5
/D6: IC1.10 ((PCINT22/OC0A/AIN0)PD6), P2.6
/MISO: IC1.16 ((PCINT4/MISO)PB4), IC2.5 (SO), P4.1
/MOSI: IC1.15 ((PCINT3/OC2A/MOSI)PB3), IC2.3 (SI), P4.5
/RESET: IC1.29 ((PCINT14/~RESET~)PC6), P4.3, R1.2, SW1.1
/RXD: IC1.30 ((PCINT16/RXD)PD0), P5.3
/SCK: IC1.17 ((PCINT5/SCK)PB5), IC2.4 (SCLK), P4.2
/TXD: IC1.31 ((PCINT17/TXD)PD1), P5.2
/XTAL1: C4.1, IC1.7 ((PCINT6/XTAL1/TOSC1)PB6), Y1.1
/XTAL2: C5.1, IC1.8 ((PCINT7/XTAL2/TOSC2)PB7), Y1.2
GND: BT1.2, C1.2, C2.2, C3.2, C4.2, C5.2, C6.2, D1.1 (K), D2.1 (K), IC1.3 (GND), IC1.5 (GND), IC1.21 (GND), IC2.2 (GND), IC2.10 (GND), IC2.11 (GND), P1.2, P5.4, P5.5, SW1.2, SW2.2
unnamed: D1.2 (A), R2.1
unnamed: D2.2 (A), R3.1
unnamed: IC1.2 ((PCINT20/XCK/T0)PD4), R2.2
unnamed: IC1.9 ((PCINT21/OC0B/T1)PD5), R3.2
unnamed: IC1.12 ((PCINT0/CLKO/ICP1)PB0), SW2.1
unnamed: IC1.14 ((PCINT2/OC1B/~SS~)PB2), IC2.8 (CSN)
unnamed: IC1.32 ((PCINT18/INT0)PD2), IC2.7 (GDO0)
unnamed: IC2.9 (ANT), P3.1
VCC: BT1.1, C1.1, C2.1, C3.1, C6.1, IC1.4 (VCC), IC1.6 (VCC), IC1.18 (AVCC), IC1.20 (AREF), IC2.1 (VCC), P1.1, P5.1, R1.1

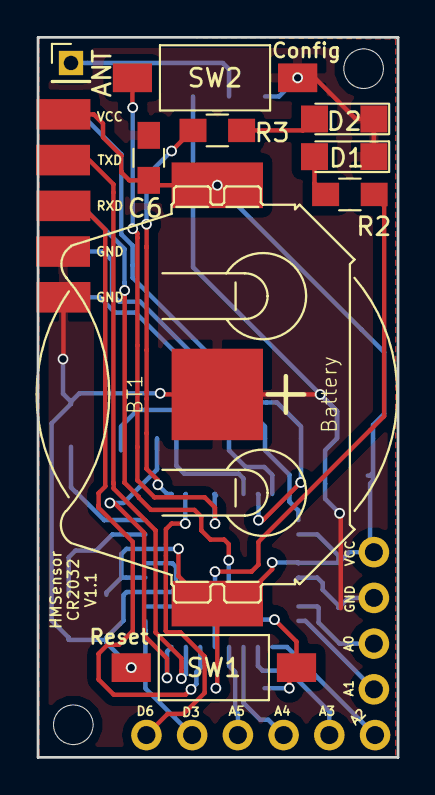
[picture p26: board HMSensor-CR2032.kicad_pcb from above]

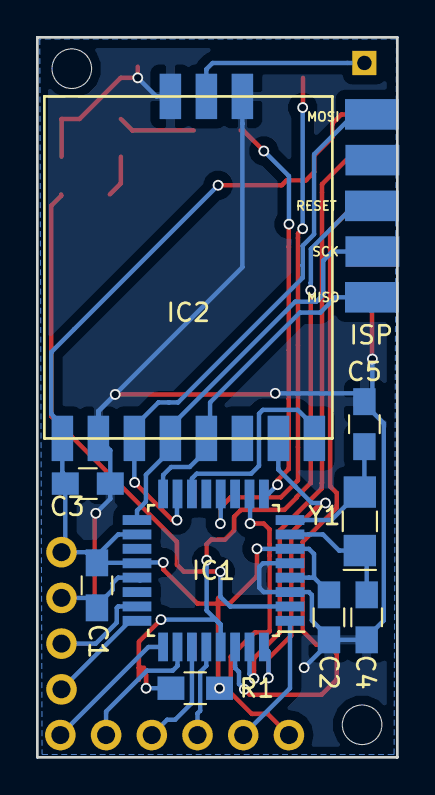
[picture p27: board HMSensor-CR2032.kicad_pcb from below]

Board: 2 copper layers, 20.0 x 40.0 mm, 22 parts (10 on the bottom side), 26 nets.

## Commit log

2017-07-06 panel added
    [1AAAHolder.FCStd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]
2017-07-07 try to fix panel problem with 18650 board
    [18650Holder-B.Cu.gbl, 18650Holder-B.Mask.gbs, 18650Holder-B.SilkS.gbo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]
2017-08-08 relay board added
    [RelayBoard-B.Cu.gbl, RelayBoard-B.Mask.gbs, RelayBoard-B.SilkS.gbo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]
2017-08-10 panel updated with relay addon
    [combined.GKO, combined.drl, combined.gbl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]
2017-08-18 fix layout problems
    [RelayBoard-B.Cu.gbl, RelayBoard-B.Mask.gbs, RelayBoard-B.SilkS.gbo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]
2017-08-18 18650 gerber fixed
    [18650Holder-B.Cu.gbl, 18650Holder-B.Mask.gbs, 18650Holder-B.SilkS.gbo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]
2017-09-05 I²C V1.1 Relay V1.1
    [I2CBoard-B.Cu.gbl, I2CBoard-B.Mask.gbs, I2CBoard-B.SilkS.gbo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]
2018-02-17 V1.1 Panel
    [combined.GKO, combined.gbl, combined.gbo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]
